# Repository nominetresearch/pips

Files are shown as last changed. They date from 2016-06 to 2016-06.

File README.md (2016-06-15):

# Pips - Guiding people through their daily routines #
----------------------

We want to help people with cognitive or sensory impairment who have difficulty organising their daily routines.  We want to offer them greater independence, make their lives more manageable, and ease the burden on care providers.

You can read more about the project in [this blog post](http://www.nominet.uk/researchblog/how-to-build-your-own-smart-iot-buttons/).

----------------------

A Pip is a round button the size of jam jar lid that lights up and beeps.  They are placed around the home in order to guide users through the sequence of tasks that make up their daily routine.  A typical routine might be: Wake up, take a shower, get dressed, feed the cat, have a cup of tea.  Each step would have an accompanying Pip placed nearby.

The Pips system is designed to be simple, flexible, unobtrusive, and connected.

*Simple* - Each Pip corresponds to a single task.  A Pip lights up and beeps to show that a task needs to be done.  Once the Pip is pressed it turns off and the next Pip in the routine is activated.

*Flexible* - Pips are customisable.  A variety of colours should be available along with relevant icons or text as a reminder of the task.  For example a Pip in the bathroom can be blue with a toothbrush icon.  Their type of beeping can also be configured.  Pips can be combined to suit the user's existing daily routine and the system can be extended and adapted as the user’s condition changes.  Routines are set up in a simple JSON file.

*Unobtrusive* - Pips can be considered to be little light-up alarm clocks that reset daily. They provide guidance but allow for plenty of flexibility in a routine.

*Connected* -  The Pips system can be extended to alert care providers via email or text message if any part of the routine isn't completed.  For example, if the cat hasn’t been fed the system can send a text message to a neighbour asking to drop in and help.

# The Pips Prototype #
----------------------

This prototype is built around the Light Blue Bean microcontroller. The Light Blue Bean is a Bluetooth low energy enabled prototyping board.  It waits in a low powered idle mode until a message is received.  Upon receiving a message it will wake up and activate the buzzer and LED according to the message payload.  When the switch is pressed it will send a message to say that event has occurred before returning to idle mode.

Additionally the system requires a ‘gateway’ which runs the software to coordinate Pip behaviour. This can be a laptop or a Raspberry Pi.

Software:

+ The Light Blue Bean code is written in C and runs an arduino sketch
+ The hub code is written in node.js and runs routines which can be configured in JSON
+ Message handling between the hub and pips is done through MQTT. Mosquito runs on the hub device to act as an MQTT broker.
+ A proxy (written in node.js) handles communication between the queues and the Pips via bluetooth.

# Contents of this repository #
-----------------------

## Software ##

All of the software required to make this system work.

### pip ###
The software that runs on the Pip device.

### gateway ###
The software which runs on a raspberry pi to coordinate the behaviour of Pips via bluetooth.

### test ###
Several scripts that will make it easier to test your gateway setup and your Pips devices.

## Hardware ##

This folder contains instructions and resources for building Pips.

### casing ###
The design for the casing which can be 3D printed.

### wiring diagram ###
An image and fritzing file that describes the circuit diagram for a Pip.

### Pips Construction Manual ###
A guide with plenty of pictures describing how to assemble a Pip.

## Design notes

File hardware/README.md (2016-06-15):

# Hardware #
-----

### casing ###
The source files, ".fcstd" in FreeCAD_src/ are source files created by & for editing by [FreeCAD](http://www.freecadweb.org/) which is free & open-source, available for Windows + Mac + Linux.

The intermediate and result files ".stl" are the standard data-transmission format for sending to a 3-D printing service.

The casing is split into components (intermediate/) to make the design more modular & hence more manageable. These components are assembled to make a final model (result/pip_box_assembly.stl).

Visual renders of each component are also available in rendered/ in .png format.

### wiring diagram ###
An image and [fritzing](http://fritzing.org/home/) file that describes the circuit diagram for a Pip.

### Pips Construction Manual ###
A guide with plenty of pictures describing how to assemble a Pip.

# Shopping List #
-----
Here is the list of components that you'll need in order to constuct a Pip.

**Pip:**

+ 3D Printed Casing (£35.61 from [i.materialise](https://i.materialise.com/creationcorner))
+ [Light Blue Bean Microcontroller](https://punchthrough.com/bean/)
+ [Piezo Buzzer](http://cpc.farnell.com/pro-signal/abi-033-rc/piezo-buzzer-pcb/dp/LS03803?in_merch=Featured%20Products)
+ [Battery Holder](http://cpc.farnell.com/pro-power/23vb11a/battery-holder-1xaa-150mm-lead/dp/BT03704)
+ [Big Dome Push Button](https://www.coolcomponents.co.uk/big-dome-push-button-blue.html?gclid=CJztspP-zMICFYHLtAodjioAZQ)
+ 4 resistors (1x10Ω, 1x100Ω, 1x1kΩ, 1x10kΩ)
+ LED in [Blue](http://uk.rs-online.com/web/p/visible-leds/7133968/), [Red](http://uk.rs-online.com/web/p/visible-leds/2285073/), or [Amber](http://uk.rs-online.com/web/p/visible-leds/7134018/) 
+ [Stripboard](http://uk.rs-online.com/web/p/stripboards/2065841/)
+ [3v AA battery](http://cpc.farnell.com/varta/craa/battery-lithium-aa-3v/dp/BT01078) (Note - this is not a normal 1.5v AA battery)
+ [Microswitch](http://uk.rs-online.com/web/p/microswitches/7294918/)
+ [Socket screw](http://uk.rs-online.com/web/p/socket-screws/0529911/)

**Miscellaneous Things:**

+ glue
+ electrical tape
+ wire
+ a couple more screws

**Tools:**

+ Soldering Iron
+ Wire cutters
+ Allen Key
+ Screw driver
+ Little spanner
+ Drill
+ Hacksaw

**Gateway:**

A laptop with an internet connection and bluetooth connectivity

\- OR -

Raspberry Pi (with wifi/ethernet connection)
Bluetooth dongle (If you don’t have a raspberry pi 3)

**Costs:**

Per pip approx £75

Most of that is:

+ £35 for 3D printing
+ £20 for the board
+ £8 for the button
+ £7 for the battery

£5 for all the other stuff (which you might have lying around anyway)

There’s a lot of opportunity to make this cheaper!

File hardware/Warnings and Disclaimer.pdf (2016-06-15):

IMPORTANT: PLEASE RETAIN THIS INFORMATION FOR FUTURE REFERENCE

### Safety warnings

1. Do not place any metal object across the battery terminals as this can short circuit and heat the battery. This can cause a risk of burn or fire.
2. Do not place any metal objects across the printed circuits on the board as this can cause a short circuit damaging your device.
3. Do not use your device in water or with wet hands.
4. Please avoid handling the device circuit board while plugged into a power supply.
5. All components of your device should comply with the relevant standards and should be marked accordingly.
6. Please do not leave your device within reach of children under 8 years of age.
7. Please operate your device in a well ventilated room.
8. Only connect your device to a power supply rated at 3 Volts.
9. Please do not store or use your device in extremely hot or cold environments.

### Battery warnings

- Do not try to charge normal (non-rechargeable) batteries. Please do not mix different types of batteries or mix new and used batteries
- Please use batteries of the same or equivalent type as those recommended
- Please insert batteries the correct way round (with the correct polarity)
- Please remove spent batteries from the battery holder
- Do not short-circuit the battery supply terminals, for example by placing a metal object across the terminals
- Only use Zinc or Alkaline batteries with your Device
- Please do not use rechargeable batteries

### Disclaimer

All content on our Website are provided on an ‘as is’ and ‘as available’ basis. We do not make any representation or give any warranty (whether express or implied) in respect of our Website or its content, including, without limitation, any advice given (on a personal or general basis) on or via the Website.

Nothing in these Terms shall restrict your statutory rights. We do not accept liability for damage to your computer system or loss of data that results from your use of the Website. We do not guarantee or warrant that any material available for downloading from our Website will be free from infection, viruses and/or other code that has contaminating or destructive properties. You are responsible for implementing sufficient procedures and virus checks (including anti-virus and other security checks) to satisfy your particular requirements for the accuracy of data input and output. You are responsible for ensuring that your computer system meets all relevant technical specifications necessary to use our Website and is compatible with our Website.

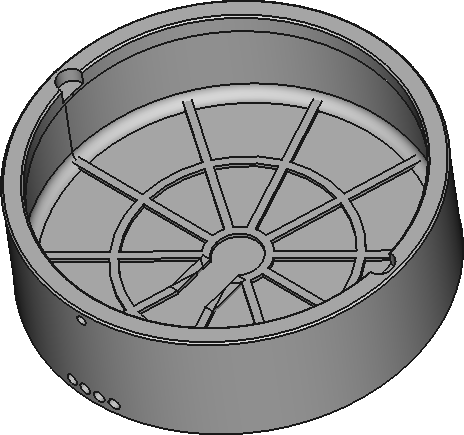
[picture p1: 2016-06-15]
hardware/casing/rendered/pip_box.png

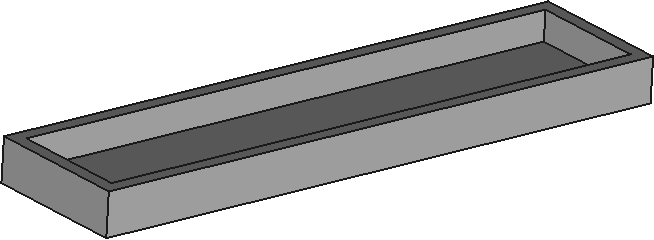
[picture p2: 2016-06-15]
hardware/casing/rendered/batteryholder.png

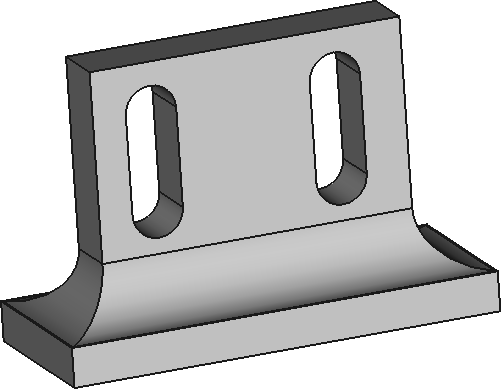
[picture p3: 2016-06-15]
hardware/casing/rendered/microswitch_mount.png

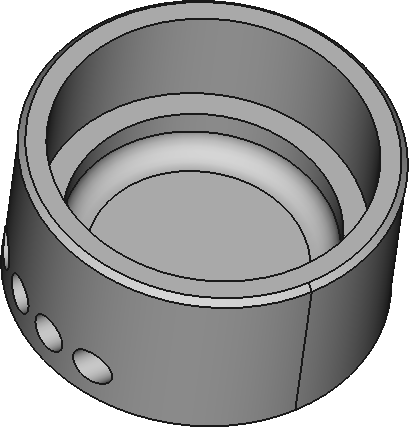
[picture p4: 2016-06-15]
hardware/casing/rendered/speakerholder.png

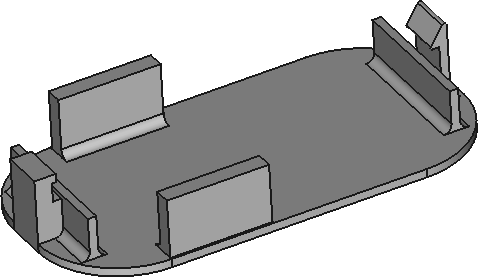
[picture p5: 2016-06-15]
hardware/casing/rendered/beanholder.png

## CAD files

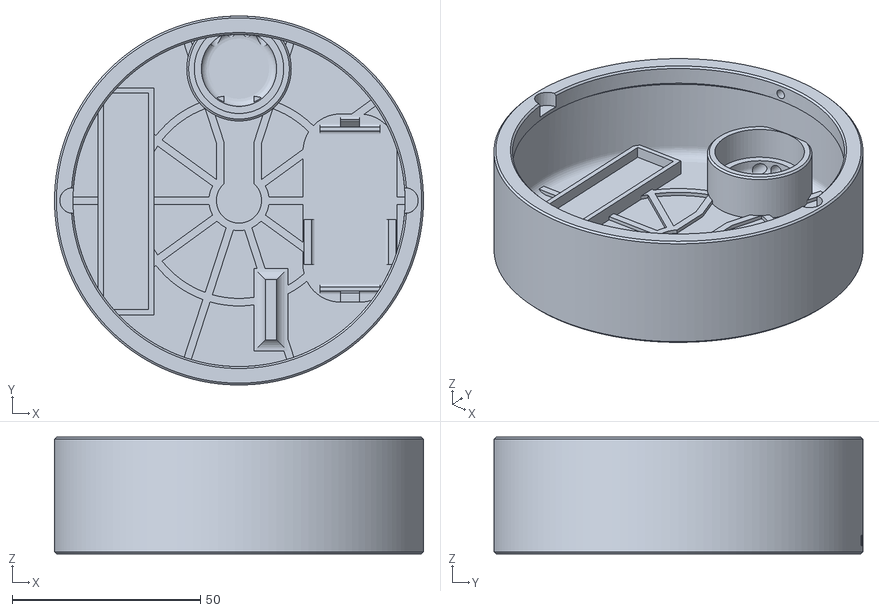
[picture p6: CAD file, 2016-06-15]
hardware/casing/result/pip_box_assembly.stl
98.0 x 98.0 x 31.0

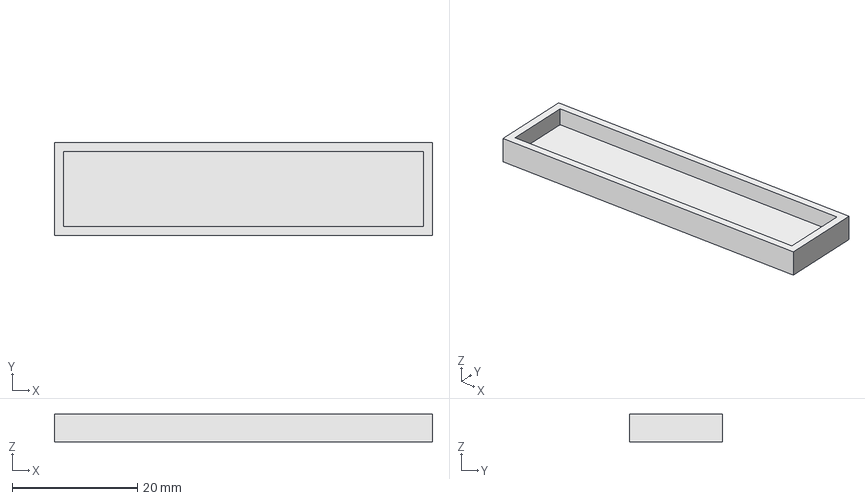
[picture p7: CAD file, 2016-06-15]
hardware/casing/FreeCAD_src/batteryholder.fcstd
60.3 x 14.8 x 4.40 mm

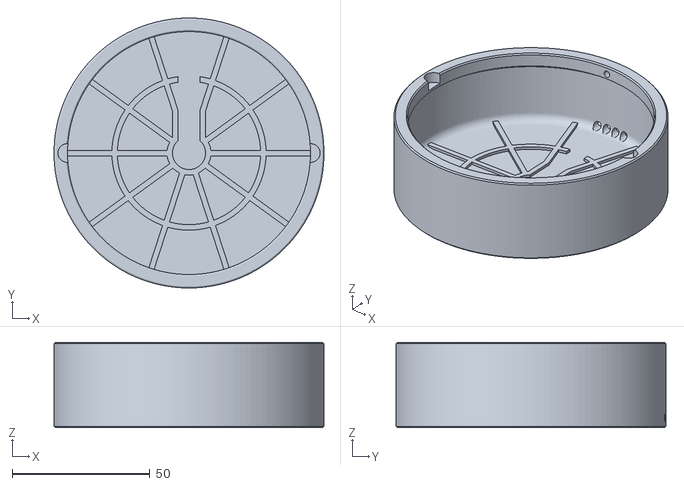
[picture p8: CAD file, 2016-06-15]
hardware/casing/intermediate/pip_box_mesh.stl
98.0 x 98.0 x 31.0

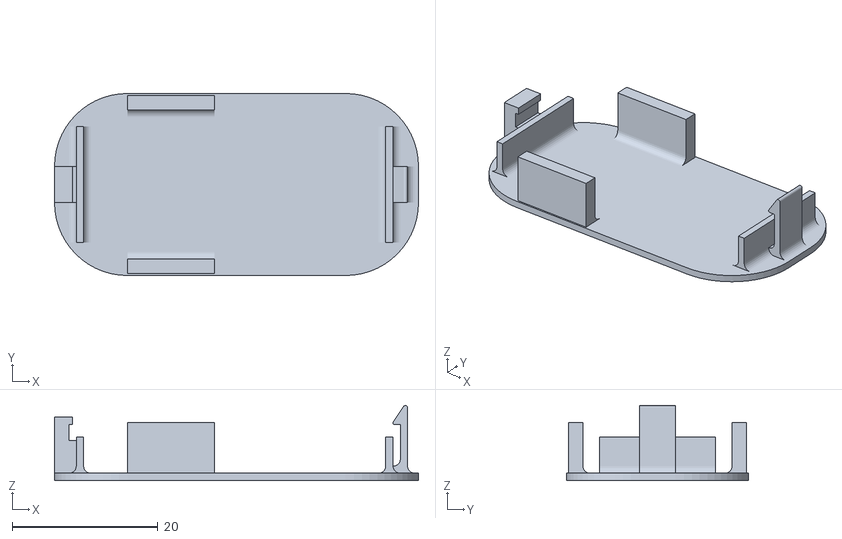
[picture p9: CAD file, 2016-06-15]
hardware/casing/intermediate/beanholder_mesh.stl
50.0 x 25.0 x 10.3

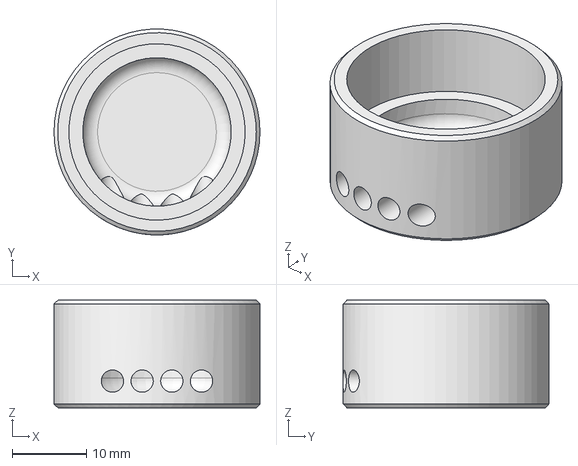
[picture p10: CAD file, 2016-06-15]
hardware/casing/FreeCAD_src/speakerholder.fcstd
27.8 x 27.7 x 14.5 mm

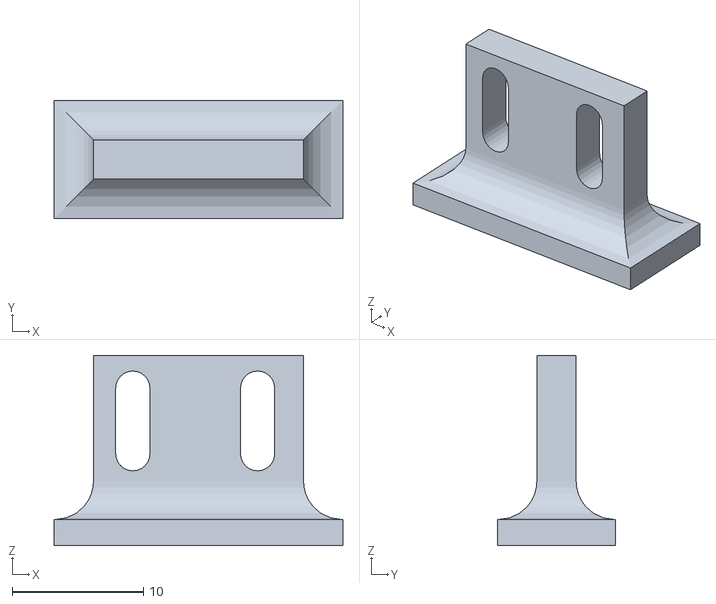
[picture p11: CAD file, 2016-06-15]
hardware/casing/intermediate/microswitch_mount_mesh.stl
22.0 x 9.00 x 14.5

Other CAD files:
hardware/casing/FreeCAD_src/pip_box_assembly.fcstd
hardware/casing/FreeCAD_src/microswitch_mount.fcstd
hardware/casing/intermediate/speakerholder_mesh.stl
hardware/casing/FreeCAD_src/pip_box.fcstd
hardware/casing/intermediate/batteryholder_mesh.stl
hardware/casing/FreeCAD_src/beanholder.fcstd

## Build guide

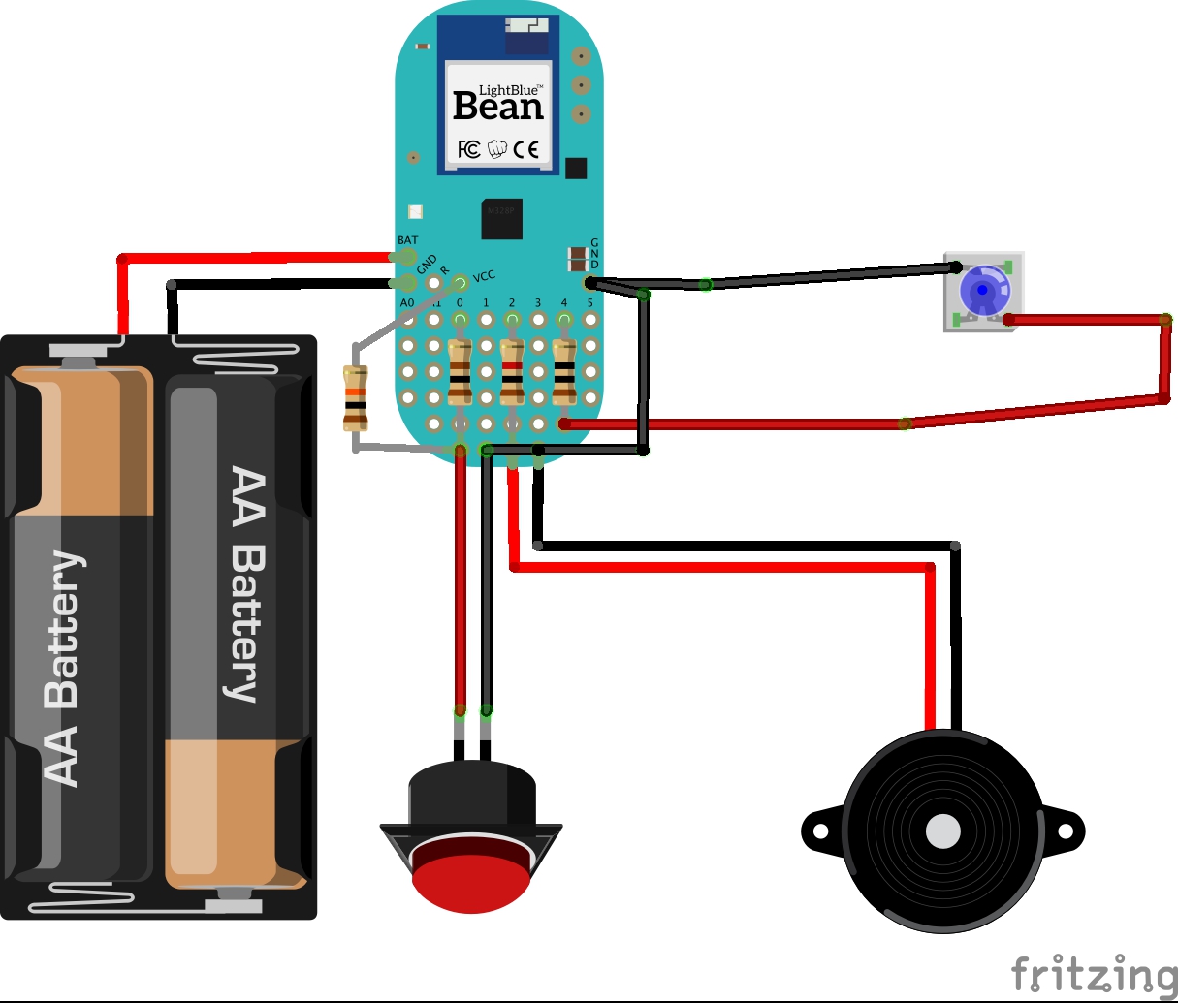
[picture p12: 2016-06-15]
hardware/wiring diagram/Pips_Sketch.jpg

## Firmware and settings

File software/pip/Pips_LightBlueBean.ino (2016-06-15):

int pipStatus = 0;
int beepPreset = 5;
int flashInterval = 5;
uint8_t defaultStatusData[3];
unsigned long currentMillis = 0;

const int ledPin = 4; //pin attached to the LED
const int buzzerPin = 2; //pin attached to the buzzer
const int buttonPin = 0;  //pin atatched to the button (pull up)

volatile boolean pin0_flag = 0; //Flag representing the button being pressed

//fucntion invoked by interupt when the button is pressed
void pin0_isr() {
  pin0_flag = 1;
}


void setup() 
{
  //Set pin attached to the LED
  pinMode(ledPin, OUTPUT);

  //Set pin attached to the buzzer
  pinMode(buzzerPin, OUTPUT);

  //Initialize the pushbutton pin as an input and set it to high
  pinMode(buttonPin, INPUT); 
  digitalWrite(buttonPin, HIGH);

  //Attach a change interrupt to the pin attached to the button
  Bean.attachChangeInterrupt(buttonPin, pin0_isr);
  
  pin0_flag = 0; 

  //Set the name of the bean to PIP
  //TODO: might need to assign a suffux to the name for easy recognition. 
  //Maybe the suffix should identify the type of task the button configured to alert for. 
  char idString[20];
  sprintf(idString, "PIP");
  Bean.setBeanName(idString);
  Bean.setLed(0,0,0);

  //Enable the bean to wake the ATMEGA328 on luetooth connection
  //It would be more desiderable to wake the ATMEGA on a scratch change notification instead
  //but this is not currently supported by the Light Blue Bean 
  Bean.enableWakeOnConnect( true );

  //Set the default parameters of the pip 
  setDefaultState();
}


/*
* Set the pip into the default state
 */
void setDefaultState()
{   
  defaultStatusData[0] = 3; //Pip is in a unknown state
  defaultStatusData[1] = 1; //Beep preset 1
  defaultStatusData[2] = 5; //500 millisecondsfor each flash
  
  //Set the scratch with the default parameters
  Bean.setScratchData(2, defaultStatusData, sizeof(defaultStatusData));
  
  //Disable buzzer
  noTone(buzzerPin);
  
  //Disable led
  digitalWrite(ledPin, LOW);
  
  pin0_flag = 0; 
}


/*
 * Control the LED component of the pip
 * interval is the time in milliseconds between on and off states
 */
void ledController(int interval){
  static unsigned long previousMillis = 0;
  static boolean on = false;
  
  if(currentMillis - previousMillis > interval) {
    // save the last time you blinked the LED 
    previousMillis = currentMillis;   
    if (on) {
      digitalWrite(ledPin, HIGH);  
      on = !on;
    } else {
      digitalWrite(ledPin, LOW);
      on = !on;
    }
  }
  
}

/*
 * Control the buzzer component of the pip
 * interval is the time in milliseconds between sound alerts
 * frequency is the frequency in Hz 
 */
void buzzerController(int beepPreset) {
  static unsigned long previousMillis = 0;
  static boolean on = false;

  /*
   * Determine which beep preset is to be used.  If an unknown preset
   * is used then we default to the same as preset 1
   */

  switch (beepPreset){
    
    //Case 1: 1 Beep at 1Khz for 100ms every 1s
    case 1:  
      if(currentMillis - previousMillis > 500) {
        previousMillis = currentMillis;   
        if (on) {
          tone(buzzerPin, 1000, 100); 
          on = !on;
        } else {
          noTone(buzzerPin);
          on = !on;
        }
      }
      break;
    //Case 2: 3 Beeps incrementing at 500hz for 200ms separated by 400ms every 1s  
    case 2:
      if(currentMillis - previousMillis > 1000) {
        previousMillis = currentMillis;   
        if (on) {
          tone(buzzerPin, 500, 200);
          delay(400); 
          tone(buzzerPin, 1000, 200);
          delay(400); 
          tone(buzzerPin, 1500, 200);
          delay(400);
          on = !on;
        } else {
          noTone(buzzerPin);
          on = !on;
        }
      }
      break;    
    //Case 3: 3 Beeps at 500hz for 200ms separated by 400ms every 1s  
    case 3:
      if(currentMillis - previousMillis > 1000) {
        previousMillis = currentMillis;   
        if (on) {
          tone(buzzerPin, 4000, 200);
          delay(400); 
          tone(buzzerPin, 4000, 200);
          delay(400); 
          tone(buzzerPin, 4000, 200);
          delay(400);
          tone(buzzerPin, 4000, 600);
          delay(400);
          on = !on;
        } else {
          noTone(buzzerPin);
          on = !on;
        }
      }
      break;
      //Case 4: C Major scale every 1s  
    case 4:
      if(currentMillis - previousMillis > 1000) {
        previousMillis = currentMillis;   
        if (on) {
          tone(buzzerPin, 261.63, 200);
          delay(400); 
          tone(buzzerPin, 293.66, 200);
          delay(400); 
          tone(buzzerPin, 329.63, 200);
          delay(400);
          tone(buzzerPin, 349.23, 200);
          delay(400);
          tone(buzzerPin, 392.00, 200);
          delay(400);
          tone(buzzerPin, 440.00, 200);
          delay(400);
          tone(buzzerPin, 493.88, 200);
          delay(400);
          tone(buzzerPin, 440.00, 200);
          delay(400); 
          tone(buzzerPin, 392.00, 200);
          delay(400);
          tone(buzzerPin, 349.23, 200);
          delay(400);
          tone(buzzerPin, 329.63, 200);
          delay(400);
          tone(buzzerPin, 293.66, 200);
          delay(400);
          tone(buzzerPin, 261.63, 600);
          delay(400);
          on = !on;
        } else {
          noTone(buzzerPin);
          on = !on;
        }
      }
      break;
    default:
      if(currentMillis - previousMillis > 500) {
        previousMillis = currentMillis;   
        if (on) {
          tone(buzzerPin, 1000, 100); 
          on = !on;
        } else {
          noTone(buzzerPin);
          on = !on;
        }
      }
      break;  
  }

}


/*
 * Checks the flag representing the button being pressed
 * and handle the button-press action 
 */
void buttonController(){
  if(pin0_flag == 1) {
    //Interrupt received, turn ISR off
    Bean.detachChangeInterrupt(buttonPin);
    pin0_flag = 0;  
    //Debounce
    delay(250);
    
    //Blink the onboard LED Green
    Bean.sleep(500);
    Bean.setLed(0, 255, 0);
    Bean.sleep(500);
    Bean.setLed(0, 0, 0);

    //Update the scratch data with the new status (off)
    ScratchData statusData = Bean.readScratchData(2);
    statusData.data[0] = 0;
    Bean.setScratchData(2, (uint8_t*) & statusData.data, sizeof(statusData.data));
    //The status data is also pushed to the scratch from where the client (pips_gateway_BLT_procy) receives notifications (button pressed)
    
    //Flip the state (Hack)
    statusData.data[0] = 3;
    Bean.setScratchData(1, (uint8_t*) & statusData.data, sizeof(statusData.data));
    statusData.data[0] = 0;
    Bean.setScratchData(1, (uint8_t*) & statusData.data, sizeof(statusData.data));
    
    //Test delay to see if the button press has been notified
    delay(1000);
    
    //Turn on the interrupt
    Bean.attachChangeInterrupt(buttonPin, pin0_isr);
  } 
}

/*
 * Show the status of the pip using the onboard LED
 * Blinking blue light indicates activity
 * TODO: This function could be expanded to indicate error states
 */
void statusBlink(int interval){
  static unsigned long previousMillis = 0;
  static boolean on = false;
  
  if(currentMillis - previousMillis > interval) {
    // save the last time you blinked the LED 
    previousMillis = currentMillis;   

    LedReading rgbSetting;
    rgbSetting = Bean.getLed();
    if (on) {
      Bean.setLed(0, 0, 0); 
      on = !on;
    } else {
      Bean.setLed(0, 0, 255);
      on = !on;
    }
  }
}

/*
 * Function to control the transition of the pip to sleep mode
 * timeout is the time in millisecond that pe pip is allowe to be
 * in an unknown state
 */
void sleepController(int timeout){
  static unsigned long previousMillis = 0;
  static boolean initialised = false;
  
  if (!initialised) { 
    previousMillis = currentMillis;
    initialised = true;
  }

  if (initialised & (currentMillis - previousMillis > timeout) & ((pipStatus == 0) || (pipStatus == 3))) {
    Bean.setLed(0, 0, 0);
    initialised = false;
    setDefaultState();
    Bean.sleep( 0xFFFFFFFF );
  }
}


/*
 * Update the internal variables defining the pip status by reading the 
 * information from the BLE Scratch data
 */
void statusController(int interval){
  //read required status from BLE scketch 2
  static unsigned long previousMillis = 0;
  ScratchData statusData2 = Bean.readScratchData(2);
  
  if (pipStatus != statusData2.data[0]) {
   pipStatus = statusData2.data[0];
   beepPreset = statusData2.data[1];
   flashInterval = statusData2.data[2];
  }
   if ((currentMillis - previousMillis > interval) & (pipStatus != 0))  {
     previousMillis = currentMillis;  
     Bean.setScratchData(1, (uint8_t*) & statusData2.data, sizeof(statusData2.data));
   }
}


//the loop routine runs over and over again forever:
void loop() 
{
  currentMillis = millis();
  statusController(1000);
  if (pipStatus == 1) { 
    buttonController();
    ledController(flashInterval*100);
    buzzerController(beepPreset);
  }

  statusBlink(500);

  sleepController(10000); 
} 
